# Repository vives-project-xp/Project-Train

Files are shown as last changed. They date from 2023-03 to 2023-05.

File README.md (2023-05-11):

# Project-Train 
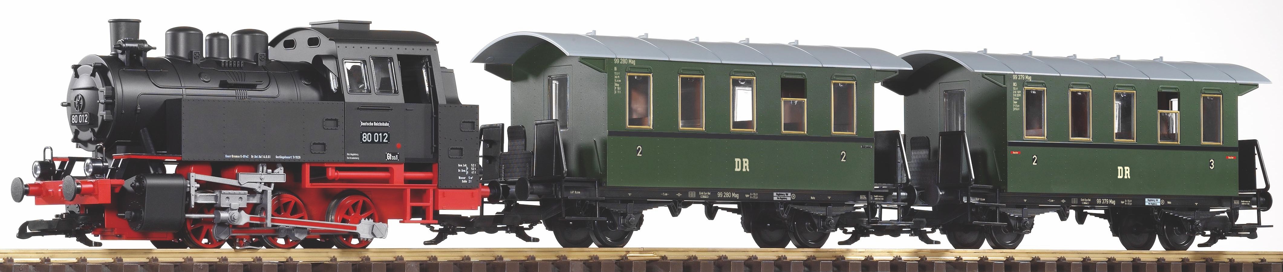
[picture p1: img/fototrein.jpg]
Trein

## Doel project
Ons project zal worden gebruikt in een escape room. 
De bedoeling is dat er allerlei dingen gebeuren in de kamer om de sperlers
hun aandacht te trekken. Onze trein zal daar bij horen.
De trein zal in een tijd van 10sec naar de overkant van de kamer 
moeten rijden. Dit zal allemaal automatisch gebeuren. 
Ook zal er een ledstip die aan de muur gangt de trein moeten volgen.

### H-Brug
Aan de hand van de H-Brug zullen we de trein aumtomatisch doen rijden. De snelheid
en de richting waarin de trein rijdt kan worden bepaald. De trein wordt geleverd met 
een draai knop om de snelheid en richting te bepalen de H-Brug zal deze dan vervangen.
Doordat we onze componenten te laat binnen kregen en een snelle oplossing moesten zoeken hiervoor
hebben we een andere component gebruikt. 

### Ledstrip
De led strip zal de trein moeten volgen zodat de aandacht
van de spelers naar de trein gaat. Dit zal gebeuren aan de hand van 
sensors die onder de trein staan. Zo kunnen we perfect weten waar de trein zich
bevint en kunnen we de ledstip programeren. We maken gebruik van een infrarood LED en een sensor. Wanneer er een object, de trein in ons geval, over deze LED en sensor rijdt zal de sensor een digitale '1' uitsturen.
In totaal hebben we 8 LEDs en sensoren, hierdoor krijgen we 8 nulletjes en eentjes binnen. Wanneer er dus een reeks van eentjes binnenkomt weten we dat de trein zich daar bevindt. Doordat we weten waar de trein zich bevindt 
kunnen we zo de LEDs aansturen om te branden waar we een '1' binnenlezen en niet te branden waar we een '0' binnenlezen.

### De sensor 
De sensoren die zich onder de trein bevinden zullen uit een fototransistor en
een infrarood led bestaan. Wanneer de trein over de sensor rijdt zal
er door de weerkaatsing van het licht een signaal worden binnengelezen. Dit signaal
kunnen we dan gebruiken. Omdat we heel wat sensors hebben gaan we deze binnen 
lezen aan de hand van schuifregisters.

### Lichten in de trein
Dit is even op hold gezet omdat er balangrijkere dingen waren maar, de bedoeling was dat
er 2 koperen staven op het spoor kwamen te liggen die verbonden zijn met een DC-DC convertor.
Hierop komen 2 veren die vasthangen aan de laatste wagon die ervoor zorgt dat de schakeling in de 
wagon voeding krijgt. De staven lopen niet helemaal door, daarom zou er een condensator in de schakeling 
zitten die na het opladen en het verlaten van de koperen staven zorgt dat de schakeling nog spanning heeft voor derest van het traject.

### Video en presentatie
Voor ons project hebben we ook een video moeten maken. De link naar deze video kan je hier terugvinden:

https://vivesonline-my.sharepoint.com/personal/r0946707_student_vives_be/_layouts/15/onedrive.aspx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

Ook hebben we een presentatie moeten maken. De link naar die presentatie kan je ook hier terugvinden:

https://vivesonline-my.sharepoint.com/:p:/r/personal/r0946707_student_vives_be/_layouts/15/Doc.aspx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

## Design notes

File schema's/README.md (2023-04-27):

# Uitleg schema's
## Sensor
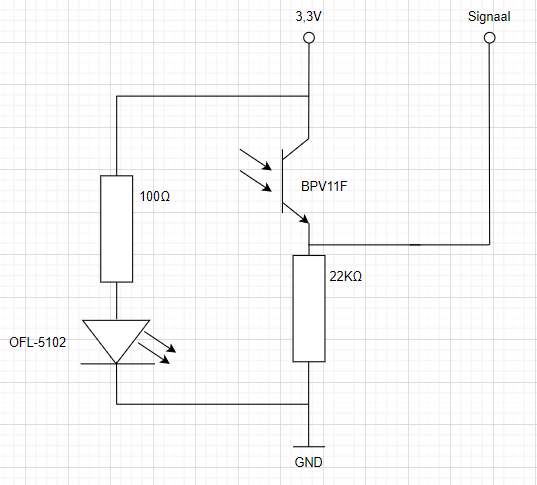
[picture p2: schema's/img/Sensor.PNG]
Schema sensor


Dit schema wordt gesoldeerd op een gaatjes print, deze zullen dan tussen
het spoor komen te liggen. Het infrarood licht van de LED zal worden weerkaatst als de trein
er over rijdt waardoor dit licht valt op de fototransistor. Deze zal in geleiding 
treden waardoor de spanning volledig over de weerstand(22kΩ) komt te staan. 
Nu krijg je een logisch '1' op de signaalpin. Dit signaal wordt aangesloten aan een [schuifregister](#aansluit-schema-esp32-devkit).

## H-Brug
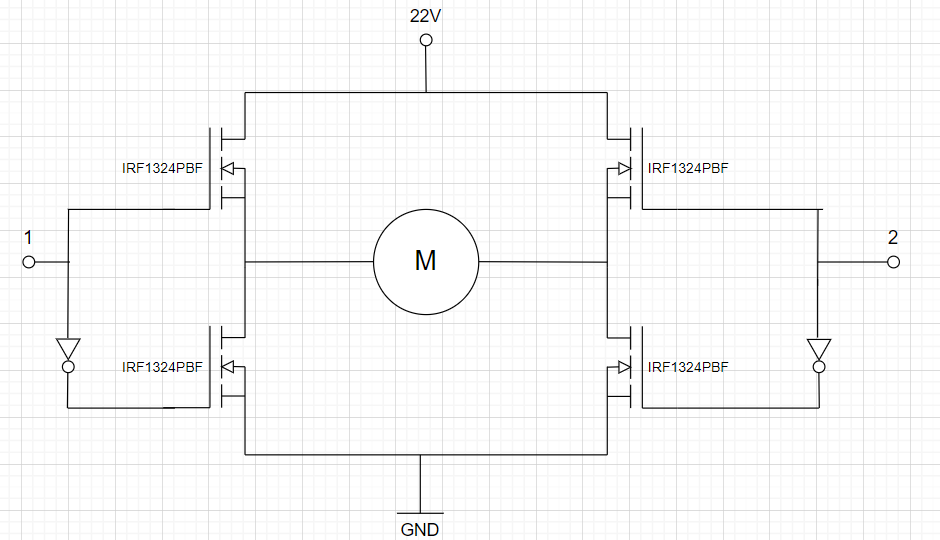
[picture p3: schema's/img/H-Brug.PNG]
H-Brug schakeling


De H-Brug wordt gebruikt om de trein te doen rijden. Hiermee kan je de snelheid en de richting
van de trein bepalen. Aan de pinnen 1 en 2 wordt een logisch '0' of een PWM signaal gelegd. De richting 
van de motor hangt af van welke pin een PWM signaal bavat. De ander pin moet verplicht een logisch '0' zijn 
omdat je anders met een kortsluiting zit. De snelheid van de trein wordt bepaald door je PWM signaal.
In ons geval nemen we een PWM met duty cycle van 66%. Hoe groter deze duty cycle is hoe sneller de
motor zal draaien. 

## Aansluit schema ESP32 devkit
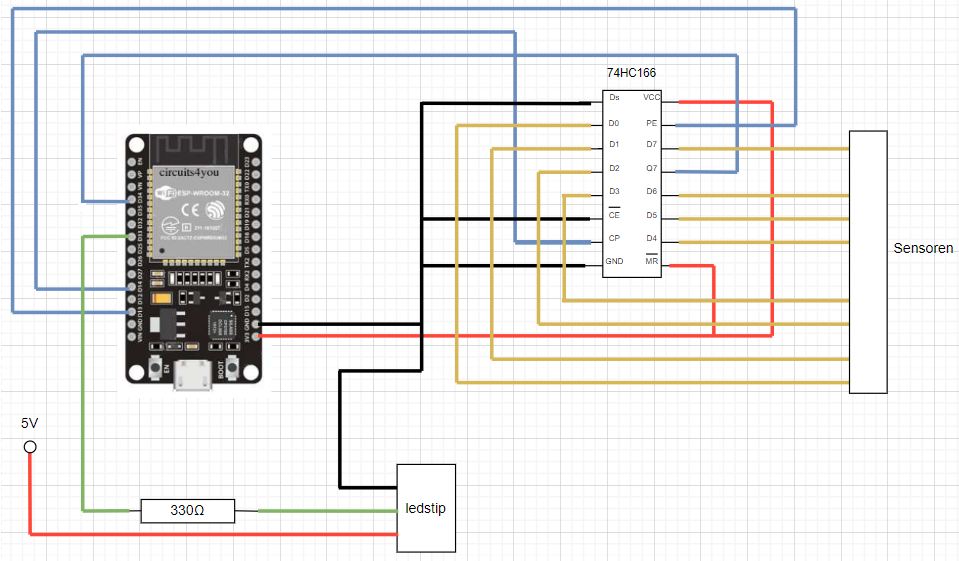
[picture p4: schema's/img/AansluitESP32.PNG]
ESP32 aansluit schema


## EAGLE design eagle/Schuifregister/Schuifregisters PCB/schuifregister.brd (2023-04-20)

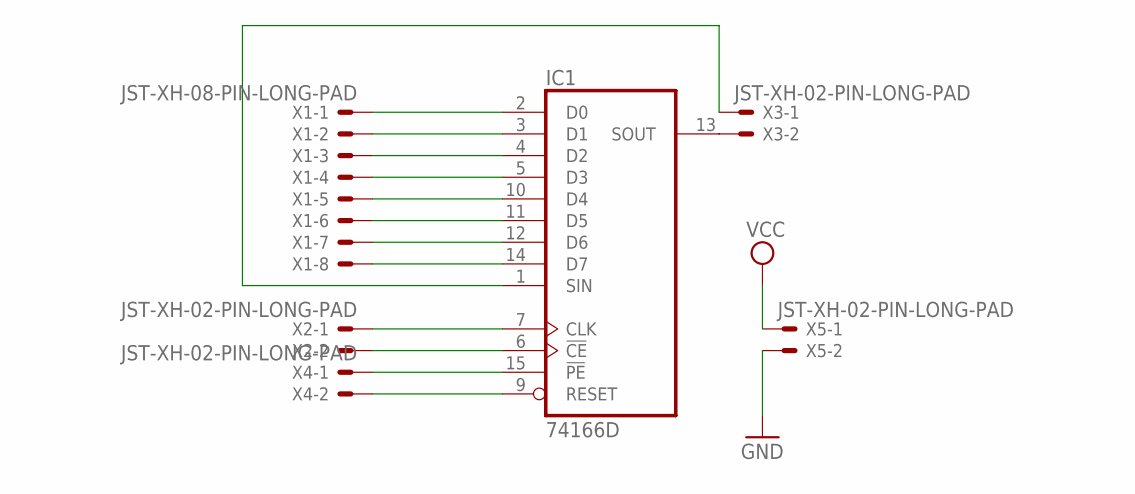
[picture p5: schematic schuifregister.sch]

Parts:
IC1: 74166D; SO16
X1: JST-XH-08-PIN-LONG-PAD; JST-XH-08-PACKAGE-LONG-PAD
X2, X3, X4, X5: JST-XH-02-PIN-LONG-PAD; JST-XH-02-PACKAGE-LONG-PAD

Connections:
GND: IC1.8 (GND), X5.2
unnamed: IC1.2 (D0), X1.1
unnamed: IC1.3 (D1), X1.2
unnamed: IC1.4 (D2), X1.3
unnamed: IC1.5 (D3), X1.4
unnamed: IC1.10 (D4), X1.5
unnamed: IC1.11 (D5), X1.6
unnamed: IC1.12 (D6), X1.7
unnamed: IC1.14 (D7), X1.8
unnamed: IC1.6 (!CE), X2.2
unnamed: IC1.7 (CLK), X2.1
unnamed: IC1.13 (SOUT), X3.2
unnamed: IC1.1 (SIN), X3.1
unnamed: IC1.9 (RESET), X4.2
unnamed: IC1.15 (!PE), X4.1
VCC: IC1.16 (VCC), X5.1

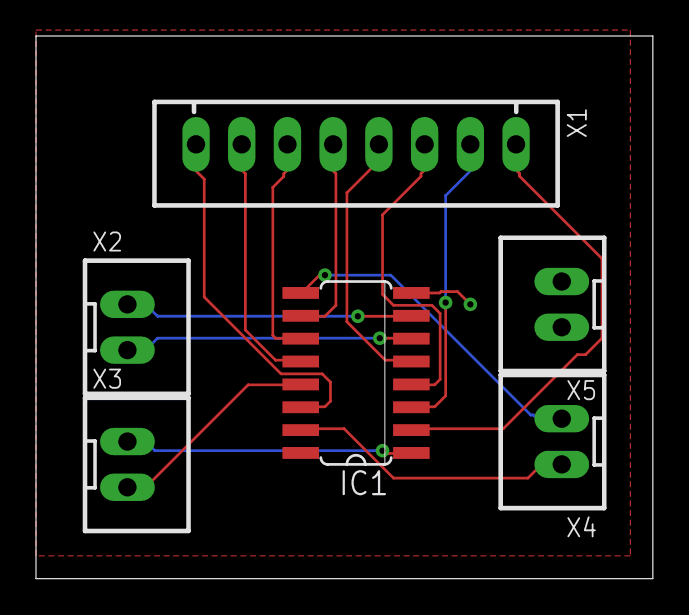
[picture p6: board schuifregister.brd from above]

Board: 2 copper layers, 34.3 x 30.1 mm, 6 parts (0 on the bottom side), 16 nets.

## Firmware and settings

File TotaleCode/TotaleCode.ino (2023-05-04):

#include <FastLED.h>
#define NUM_LEDS 50
#define DATA_PIN 33
#define Color CRGB(255,139,23);
#define Brightness 25

unsigned long previousMillis = 0; // Variable to store the previous time
const long interval = 150;

CRGB leds[NUM_LEDS];
//#define ADCPin 36
//int incomingByte = 0; // for incoming serial data
//byte bits = 1;
const int typeLength = 7;
int downFlank = 0;
int upFlank = 0;
//int aantalLeds = 4;

int ioSelect =13;
int clockPulse = 14;
int dataOut=34;
int value;


void setup() {
  Serial.begin(115200); // opens serial port, sets data rate to 9600 bps
  FastLED.addLeds<NEOPIXEL, DATA_PIN>(leds, NUM_LEDS);  // GRB ordering is assumed
  pinMode(ioSelect,OUTPUT);
  pinMode(clockPulse,OUTPUT);
  pinMode(dataOut,INPUT);
  FastLED.setBrightness(Brightness);
}
void flanks(int value){
  if(value == 1){
  }
  else{
  for(int i = 0; i <= typeLength; i++){
  
    if(((value&0x2)>>1) > (value&0x1)){
      downFlank = i+1;
    }
    if(((value&0x2)>>1) < (value&0x1)){
      upFlank = i;
    }
    value = value>> 1;
    
    } 
  }
}
void ledStrip(){
 /*for(int i = upFlank;i < downFlank+1; i++)
        { 
        leds[i] = Color;
        FastLED.show();
        leds[i] = CRGB::Black;
        delay(150);
        }*/
  for (int i = upFlank; i < downFlank + 1; i++) {
    leds[i] = Color;
    FastLED.show();
    leds[i] = CRGB::Black;
  
    // Check if it's time to change the LED color
    unsigned long currentMillis = millis();
    if (currentMillis - previousMillis >= interval) {
      // Update the previous time
      previousMillis = currentMillis;
  
      // Move to the next LED
      i++;
      }
   }
 }
/*byte bitSequentie(){
  byte dataIn=0; //uint16_t or uint32_t voor meer inputs
  digitalWrite(ioSelect,0);//laat parallele input toe
  digitalWrite(clockPulse,0);//start klok pin laag
  digitalWrite(clockPulse,1);//clock pin laag, data zit in de IC
  digitalWrite(ioSelect,1);//schakel parallele input uit en zet seriele output aan

  for (int i = 0; i < 8; i++)//overloopt alle 8 de bits verhoog dit voor meer bits
  {
    value=digitalRead(dataOut);//data digitaal binnen lezen 
    //Serial.print("waarde");
    //Serial.println(value);//waarde bit per bit weergeven 
    if (value){
      int a = (1<<i);//verschuift de bit achtereenvolgens naar de juiste plaats
      dataIn=dataIn|a;//combineert gegevens van verschoven bits om een enkel 8-bits getal te vormen
    }
    digitalWrite(clockPulse,LOW);//achter dat elke bit binnen is clock puls geven voor volgende bit
    digitalWrite(clockPulse,HIGH);
  }
}*/
void loop() {
  /* incomingByte = analogRead(ADCPin);
   int x = map(incomingByte, 0, 4095, 0, 7);
   bits = 1;
   for(int i = 0; i < x; i++){
    bits = bits * 2;
    }*/
    byte dataIn=0; //uint16_t or uint32_t voor meer inputs
  digitalWrite(ioSelect,0);//laat parallele input toe
  digitalWrite(clockPulse,0);//start klok pin laag
  digitalWrite(clockPulse,1);//clock pin laag, data zit in de IC
  digitalWrite(ioSelect,1);//schakel parallele input uit en zet seriele output aan

  for (int i = 0; i < 8; i++)//overloopt alle 8 de bits verhoog dit voor meer bits
  {
    value=digitalRead(dataOut);//data digitaal binnen lezen 
    //Serial.print("waarde");
    //Serial.println(value);//waarde bit per bit weergeven 
    if (value){
      int a = (1<<i);//verschuift de bit achtereenvolgens naar de juiste plaats
      dataIn=dataIn|a;//combineert gegevens van verschoven bits om een enkel 8-bits getal te vormen
    }
    digitalWrite(clockPulse,LOW);//achter dat elke bit binnen is clock puls geven voor volgende bit
    digitalWrite(clockPulse,HIGH);
  }
   flanks(dataIn);
   ledStrip();
   Serial.println(dataIn, BIN);

      
         
  /*Serial.println(bits, BIN);
  Serial.println(upFlank);
  Serial.println(downFlank);
  delay(100); */
}

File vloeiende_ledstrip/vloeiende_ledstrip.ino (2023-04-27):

#include <FastLED.h>
#define NUM_LEDS 400
#define DATA_PIN 33
#define Color CRGB(255,139,23);
#define Brightness 25
#define FadeDelay 20
#define PWMPin 3
CRGB leds[NUM_LEDS];
const int typeLength = 7;
int ioSelect = 13;
int clockPulse = 14;
int dataOut = 34;

void setup() {
  Serial.begin(115200);
  FastLED.addLeds<NEOPIXEL, DATA_PIN>(leds, NUM_LEDS);
  pinMode(ioSelect, OUTPUT);
  pinMode(clockPulse, OUTPUT);
  pinMode(dataOut, INPUT);
  FastLED.setBrightness(Brightness);
  pinMode(PWMPin ,OUTPUT);
}

void flanks(int value, int *startLed, int *endLed) {
  int ledCount = NUM_LEDS;
  for (int i = 0; i <= typeLength; i++) {
    if (((value & 0x2) >> 1) > (value & 0x1)) {
      *startLed = (int)(((float)i / (float)typeLength) * (float)ledCount);
    }
    if (((value & 0x2) >> 1) < (value & 0x1)) {
      *endLed = (int)(((float)i / (float)typeLength) * (float)ledCount);
    }
    value = value >> 1;
  }
}

void ledStrip(int startLed, int endLed) {
  for (int i = startLed; i <= endLed; i++) {
    leds[i] = Color;
    FastLED.show();
    delay(FadeDelay);
  }

  for (int i = endLed; i >= startLed; i--) {
    leds[i] = CRGB::Black;
    FastLED.show();
    delay(FadeDelay);
  }
  
}

/*void ledStrip(int startLed, int endLed) {
  for (int i = startLed; i <= endLed; i++) {
    leds[i] = Color;
    FastLED.show();
    delay(FadeDelay);
  }

  for (int i = endLed; i >= startLed; i--) {
    leds[i] = CRGB::Black;
    FastLED.show();
    delay(FadeDelay);
  }
  
}*/
/*void ledStrip(int startLed, int endLed) {
  for (int i = startLed; i <= endLed-1; i++) {
    leds[i] = Color;
  }
  FastLED.show();
  for (int i = startLed; i <= endLed; i++) {
    leds[i] = CRGB::Black;
  }
}*/

/*void ledStrip(int startLed, int endLed) {
  for (int i = startLed; i <= endLed; i++) {
    leds[i] = Color;
    FastLED.show();
  }
  
  
  for (int i = endLed; i >= startLed; i--) {
    leds[i] = CRGB::Black;
    FastLED.show();
  }
  
}
*/

/*void ledStrip(int startLed, int endLed) {
  for (int i = startLed; i <= endLed; i++) {
    leds[i] = Color;
    FastLED.show();
  }
  
  
  for (int i = endLed; i >= startLed; i--) {
    leds[i] = CRGB::Black;
    FastLED.show();
  }
  
}
*/
void loop() {

  
  analogWrite(PWMPin , 1023);
  int dataIn = 0;
  digitalWrite(ioSelect, 0);
  digitalWrite(clockPulse, 0);
  digitalWrite(clockPulse, 1);
  digitalWrite(ioSelect, 1);

  for (int i = 0; i < 8; i++) {
    int value = digitalRead(dataOut);
    if (value) {
      int a = (1 << i);
      dataIn = dataIn | a;
    }
    digitalWrite(clockPulse, LOW);
    digitalWrite(clockPulse, HIGH);
  }

  int startLed = 0;
  int endLed = NUM_LEDS - 1;
  flanks(dataIn, &startLed, &endLed);
  ledStrip(startLed, endLed);

  Serial.println(dataIn, BIN);
}

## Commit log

2023-03-30 PCB infrarood gerber
2023-04-05 added gerber files of schuifregister PCB
2023-04-14 PCB lichten trein
2023-04-20 Added original PCB files to te repo
    [schuifregister.brd, schuifregister.sch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]
2023-04-27 schema sensor toegevoegd
